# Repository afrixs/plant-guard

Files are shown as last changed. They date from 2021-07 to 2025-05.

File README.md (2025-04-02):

# Plant guard

Click to watch (https://www.youtube.com/watch?v=59vS7RXK-lc "Click to watch")

A simple plant watering machine.
Used parts:
  - Raspberry Pi 3 B+
  - Submersible Low Noise Motor Pump 3-6V
  - Motor driver l293d
  - Stepper motor 28BYJ-48 with driver
  - Silicon hose
  - Bucket
  - [3d-printed parts](models)
  - dupont cables, screws, ...

No sensors are used for now, you will need to set appropriate timing for the frequency and duration of the watering (Keep in mind the watering will be slower when the bucket is emptier).

Usage:
  1. Assemble using the datasheets of the components (GPIO pins for the pump driver are 5 (->IN1) and 6 (->IN2), GPIO pins for the stepper motor driver are 24, 23, 22, 27 (-> IN1, IN2, IN3, IN4)) and mount onto the bucket
  2. `ssh pi@raspberrypi.local`
  3. `git clone https://github.com/afrixs/plant-guard.git`
  4. `pip3 install python_crontab pyyaml portalocker`
  5. Set the arm to point directly outwards from the bucket
  6. `python3 plant-guard/pg_ws/src/pg_pump_crane/pg_pump_crane/pump_crane_keyboard.py`
  7. Use arrow keys to move the arm. Repeat the last arrow key stroke to stop. When the arm is above the plant being configured use 'f' key to set `angle_from`. Optionally move the arm a little bit and use 't' key to set `angle_to`. The arm will be moving between `angle_from` and `angle_to` during the watering so that water does not fall to a single spot only.
  8. Use 'p' key to start/stop the pump. Duration of pumping will be stored to `pump_dur`.
  9. Use 'Enter' key to create a watering job. Enter a name for the job and a crontab time entry
  10. The watering job is scheduled. Repeat 6.-8. for another plant
  11. Use 'l' key to list all jobs, 'd' key to delete a single job or 'x' key to delete all jobs
  12. Use 'q' or 'Esc' key to quit the job configuration client. Lock for controlling motors is released and scheduled jobs are free to run
  13. You can now use Ctrl+D to logout from ssh

Note: You may edit the jobs afterwards using `crontab -e` or `nano ~/plant_guard/jobs.yaml`.

Important note: don't turn the stepper motor manually after the first start or the configuration will be broken. If you need (or accidentally happen) to turn it, use `rm ~/plant_guard/save.txt; rm ~/plant_guard/save_backup.txt` and follow steps 5. - 12. to reconfigure (or turn the motor back to its original position, hoping the difference will not be critical).

Important note: Also when leaving the device to operate without your attendance for a longer time, prepare the place in a way that no firm or big leaves capable of blocking the movement of the arm will grow in its way.

First test was successful: Here are images of our plants before and after leaving the apartment for 9 days. I think they liked it

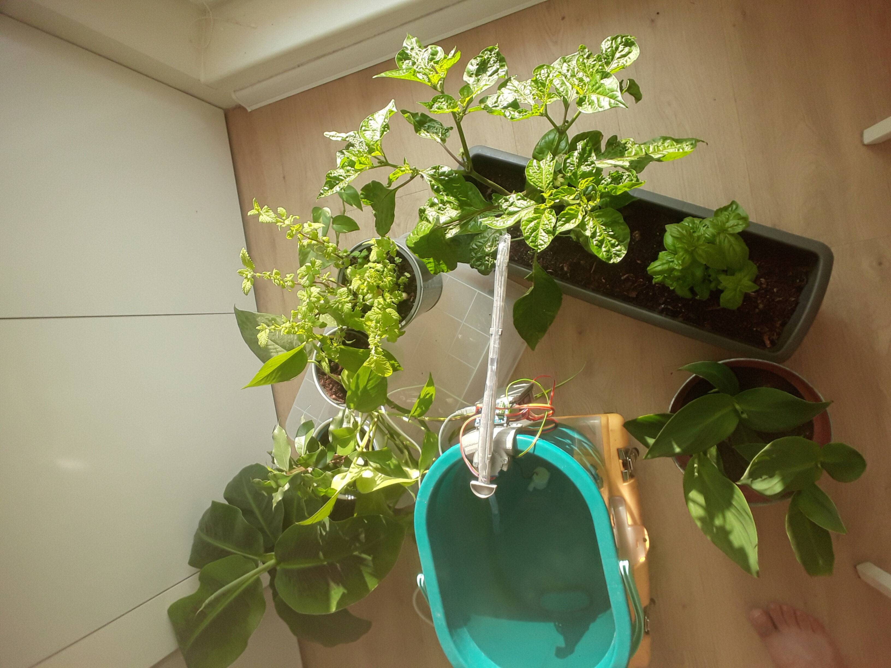
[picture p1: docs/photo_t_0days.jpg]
t = 0

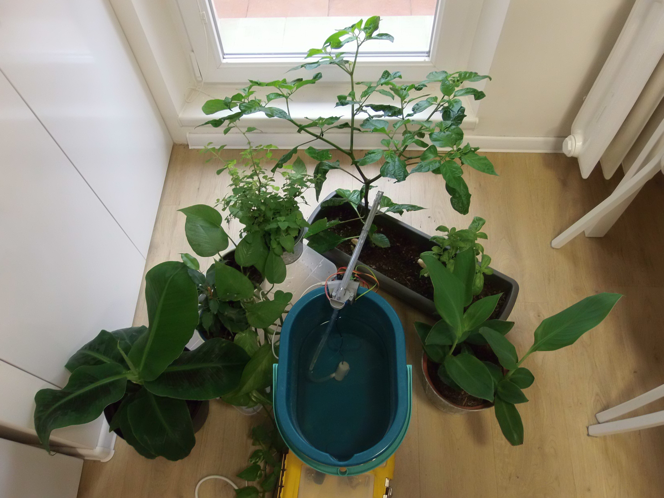
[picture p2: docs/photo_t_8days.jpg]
t = 9 days


sudo nano /boot/firmware/config.txt -> dtparam=spi=on
sudo raspi-config -> System Options -> Boot / Auto Login -> Console Autologin
sudo nano /etc/dphys-swapfile -> CONF_SWAPSIZE=4096, CONF_MAXSWAP=4096
sudo dphys-swapfile setup
mkdir .plant_guard
mkdir .ros
sudo ln -s /home/pi/.ros /root/.ros
sudo ln -s /home/pi/.plant_guard /root/.plant_guard
sudo ln -s /var/spool/cron/crontabs /root/.plant_guard_cron
tmp (TODO): nano .plant_guard/jobs.yaml
# add following 3 lines
pump_crane:
  __config: {}
  __type: pump_crane

sudo ./docker-build.bash
# or to run in background:
sudo apt install screen
sudo screen -dmS plant_guard_build /bin/bash -i -c "./docker-build.bash 2>>/root/build_docker.err 1>>/root/build_docker.out"
sudo tail -f /root/build_docker.err
# sudo screen -S plant_guard_build -X quit
Note: `docker-*.bash` must be run with `sudo`

sudo apt install screen
sudo crontab -e -> @reboot screen -DmS plant_guard bash -i -c "/home/pi/plant-guard/docker-run.bash 1>>/root/plant_guard_control_out.log 2>>/root/plant_guard_control_err.log"
sudo screen -S plant_guard -X quit

server:
```
sudo yum update
sudo yum install docker
sudo systemctl enable docker
sudo crontab -e -> @reboot sudo docker run --init --rm --net=host -p 7447:7447/tcp -p 8000:8000/tcp eclipse/zenoh:0.5.0-beta.9
```

client:
ros2 launch plantguard_bringup pump_crane_client.launch.py

testing on local machine:
sudo ./docker-build.bash --build-arg use_mocks=true
sudo ./docker-run.bash raspberry_pi:=false stream_over_internet:=false
ros2 launch plantguard_bringup pump_crane_client.launch.py stream_over_internet:=false

(for building on native system):
rosdep update --include-eol-distros
rosdep install --from-paths src --ignore-src --rosdistro iron --skip-keys libcamera -y

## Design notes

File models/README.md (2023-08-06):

# Models
These are models to be 3D-printed for the robot. Basically you need to print each `.3mf` file once.
I use [PrusaSlicer](https://www.prusa3d.com/) for slicing and generating gcode.

## Editing
Probably (unless you happen to have same bucket and components as me) you'll need to edit
some parts. Currently I suggest using [toponaming](https://github.com/FreeCAD/FreeCAD/tree/development/toponaming) branch of
FreeCAD and (to prevent headaches) **not mapping anything on 3D features**, i.e. project only geometry from sketches and
use DatumPlanes and parametric expressions to achieve proper structure, otherwise recomputing hell will come upon you
with refernces jumping from one feature to another etc.

After editing and exporting the models, there is a `Reload from disk` feature in PrusaSlicer.

After reloading from disk you will want to add supports to all overhangs under 40˚ for `arm-Arm.stl` and 50˚ for `arm-Base.stl` and to disable supports in screw and nut holes, because 3D printer usually can handle small bridges like those and much of filament and printing time can be spared. Final supports could be like what you see (green color) in the image below.

Note: I haven't printed this version of `arm-Base.stl` model (I printed just a previous buggy version where the roof for RPi and motor driver didn't lean), so maybe you will need to play with print params (increase brim etc.) to print the model successfully.

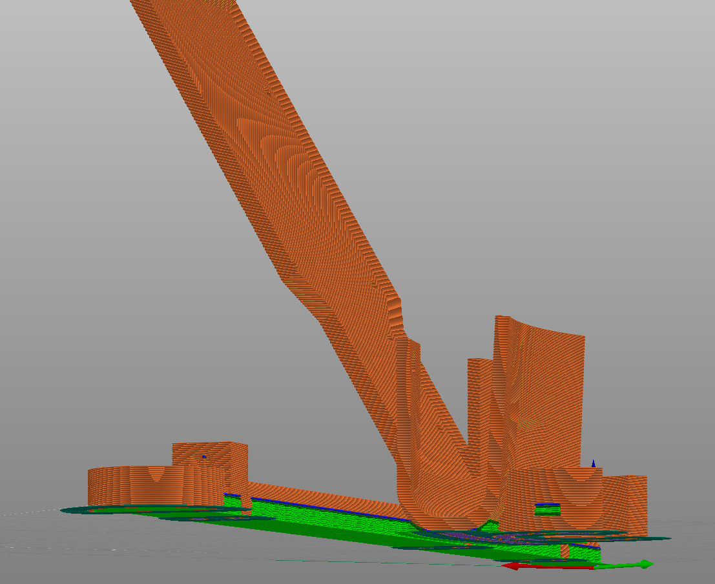
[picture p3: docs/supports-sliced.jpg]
t = 0


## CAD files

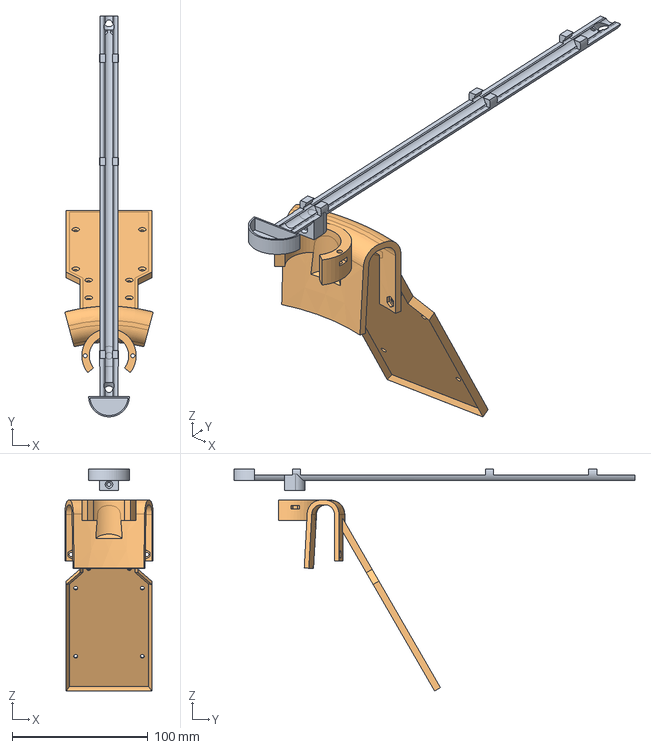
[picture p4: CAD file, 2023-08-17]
models/arm.FCStd
65.1 x 295.0 x 163.4 mm
Arm
Base

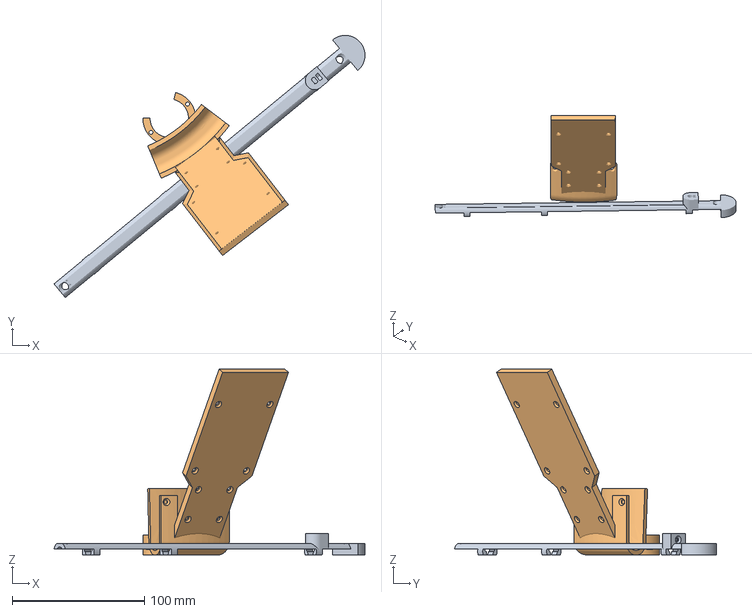
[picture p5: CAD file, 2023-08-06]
models/arm-Arm.3mf
235.3 x 198.3 x 140.5 mm
arm-Arm.stl
arm-Base.stl

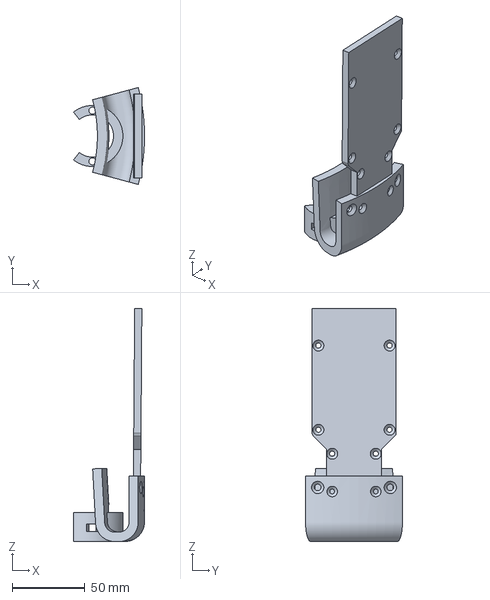
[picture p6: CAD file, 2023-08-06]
models/arm-Base.3mf
48.9 x 66.7 x 160.5 mm

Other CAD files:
models/pump-crane-plants.FCStd
models/arm-Arm.stl
models/arm-Base.stl

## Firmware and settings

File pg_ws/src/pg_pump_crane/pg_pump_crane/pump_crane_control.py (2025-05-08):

import rclpy
from rclpy.time import Duration, Time
from rclpy.node import Node
from rclpy.qos import QoSProfile, ReliabilityPolicy
from std_msgs.msg import Int32, Bool
# from pg_msgs.srv import GetJobs, EditJob
from pg_msgs.msg import MeasurementHeader
from pg_pump_crane_msgs.action import PerformJob
from pg_msgs.msg import Float64Stamped, BoolStamped
from rclpy.action import ActionServer, CancelResponse, GoalResponse
from rclpy.callback_groups import MutuallyExclusiveCallbackGroup
from rclpy.executors import MultiThreadedExecutor
from pg_pump_crane.pump_crane import PumpCrane
import portalocker
from pathlib import Path
from threading import Lock, Thread, Condition

class PumpCraneControl(Node):
  def __init__(self):
    super().__init__('pump_crane_control')

    self.angle_pub = self.create_publisher(Float64Stamped, 'angle', 1) #QoSProfile(depth=1, reliability=ReliabilityPolicy.BEST_EFFORT))
    self.pump_pub = self.create_publisher(BoolStamped, 'pump', 1)
    # TODO: pump_pub

    self.pump_crane = PumpCrane(False, stepperPosCallback=lambda pos: self.stepper_pos_callback(pos), pumpCallback=lambda pumping: self.pump_callback(pumping))
    self.pump_crane.setKeyboardListening(True)
    self.pump_crane.cleanupHW()

    self.movement_dir_sub = self.create_subscription(Int32, 'movement_dir_cmd', self.movement_dir_cmd_callback, 1)
    self.pump_sub = self.create_subscription(Bool, 'pump_cmd', self.pump_cmd_callback, 1)

    # self.get_jobs_server = self.create_service(GetJobs, 'get_jobs', self.get_jobs_callback)
    # self.edit_job_server = self.create_service(EditJob, 'edit_job', self.edit_job_callback)

    self.perform_job_server = ActionServer(
      self,
      PerformJob,
      'perform_job',
      self.perform_job_callback,
      goal_callback=self.perform_job_goal_callback,
      cancel_callback=self.perform_job_cancel_callback,
      callback_group=MutuallyExclusiveCallbackGroup()
    )

    self.pump_crane_lock = Lock()
    self.canceled_jobs = []  # cannot be a set() because UUIDs are not hashable
    self.jobs_queue = []
    self.jobs_queue_condition = Condition()
    self.current_job_goal_handle = None
    self.current_job_goal_handle_lock = Lock()

    self.watchdog_timer = self.create_timer(0.5, self.watchdog_callback)
    self.last_pump_time = None
    self.last_movement_time = None

  def destroy_node(self):
    self.pump_crane.setKeyboardListening(False)
    self.pump_crane.stopPump()
    self.pump_crane.setMovementDir(0)
    self.pump_crane.cleanup()
    try:
      self.pump_crane_lock.release()
    except:
      pass
    super().destroy_node()

  def watchdog_callback(self):
    if self.last_pump_time is not None and self.get_clock().now() - self.last_pump_time > Duration(seconds=0.5):
      self.get_logger().warn("Connection lost, stopping pump")
      self.pump_crane.stopPump()
      self.last_pump_time = None
      if self.last_movement_time is None:
        self.pump_crane.cleanupHW()
        self.pump_crane_lock.release()
    if self.last_movement_time is not None and self.get_clock().now() - self.last_movement_time > Duration(seconds=0.5):
      self.get_logger().warn("Connection lost, stopping movement")
      self.pump_crane.setMovementDir(0)
      self.last_movement_time = None
      if self.last_pump_time is None:
        self.pump_crane.cleanupHW()
        self.pump_crane_lock.release()

  def movement_dir_cmd_callback(self, msg: Int32):
    was_moving = self.last_movement_time is not None
    self.last_movement_time = self.get_clock().now() if msg.data != 0 else None
    if self.last_movement_time is not None and not was_moving and self.last_pump_time is None:
      self.pump_crane_lock.acquire()
      self.pump_crane.initHW()
    self.pump_crane.setMovementDir(msg.data)
    if self.last_movement_time is None and was_moving and self.last_pump_time is None:
      self.pump_crane.cleanupHW()
      self.pump_crane_lock.release()

  def pump_cmd_callback(self, msg: Bool):
    was_pumping = self.last_pump_time is not None
    if msg.data:
      self.last_pump_time = self.get_clock().now()
      if not was_pumping and self.last_movement_time is None:
        self.pump_crane_lock.acquire()
        self.pump_crane.initHW()
      self.pump_crane.startPump()
    else:
      self.pump_crane.stopPump()
      self.last_pump_time = None
      if was_pumping and self.last_movement_time is None:
        self.pump_crane.cleanupHW()
        self.pump_crane_lock.release()

  def perform_job_goal_callback(self, goal: PerformJob.Goal):
    self.get_logger().info(f"Received PerformJob goal: ({goal.job.angle_from}˚ <-> {goal.job.angle_to}°) x {goal.job.pump_duration} s")
    return GoalResponse.ACCEPT

  def perform_job_cancel_callback(self, goal_handle):
    self.get_logger().info(f"PerformJob goal {goal_handle.goal_id} canceling")
    with self.jobs_queue_condition:
      if goal_handle.is_active:
        self.canceled_jobs.append(goal_handle.goal_id)
        self.jobs_queue_condition.notify_all()
    return CancelResponse.ACCEPT

  def perform_job_callback(self, goal_handle):
    goal: PerformJob.Goal = goal_handle.request
    result = PerformJob.Result()

    with self.jobs_queue_condition:
      self.jobs_queue.append(goal_handle.goal_id)
      if len(self.jobs_queue) > 1:
        self.get_logger().info(f"PerformJob goal {goal_handle.goal_id} queued")
        feedback = PerformJob.Feedback()
        feedback.stage = PerformJob.Feedback.STAGE_QUEUED
        goal_handle.publish_feedback(feedback)

        while rclpy.ok() and not (goal_handle.is_cancel_requested or goal_handle.goal_id in self.canceled_jobs) and self.jobs_queue[0] != goal_handle.goal_id:
          self.jobs_queue_condition.wait()

    if rclpy.ok() and not goal_handle.is_cancel_requested:
      self.get_logger().info(f"Executing PerformJob goal {goal_handle.goal_id}...")
      self.pump_crane_lock.acquire()
      self.pump_crane.initHW()

      with self.current_job_goal_handle_lock:
        self.current_job_goal_handle = goal_handle
        feedback = PerformJob.Feedback()
        feedback.stage = PerformJob.Feedback.STAGE_APPROACHING
        goal_handle.publish_feedback(feedback)

      self.pump_crane.allowMovement()
      water_thread = Thread(
        target=self.pump_crane.water,
        args=(goal.job.angle_from, goal.job.angle_to, goal.job.pump_duration, False),
        daemon=True)
      water_thread.start()

      while rclpy.ok() and not goal_handle.is_cancel_requested and water_thread.is_alive():
        # feedback = PerformJob.Feedback()
        # feedback.current_duration = (self.get_clock().now() - start).nanoseconds / 1e9
        # goal_handle.publish_feedback(feedback)
        self.get_clock().sleep_for(Duration(seconds=0.1))
      if water_thread.is_alive():
        self.pump_crane.terminateMovement()
      water_thread.join()

      with self.current_job_goal_handle_lock:
        self.current_job_goal_handle = None
      self.pump_crane.cleanupHW()
      self.pump_crane_lock.release()

    with self.jobs_queue_condition:
      self.jobs_queue.remove(goal_handle.goal_id)
      self.jobs_queue_condition.notify_all()

      # must be inside the lock to prevent adding the uuid to canceled_jobs after the job is done
      try:
        self.canceled_jobs.remove(goal_handle.goal_id)
      except ValueError:
        pass
      if goal_handle.is_cancel_requested:
        goal_handle.canceled()
      else:
        goal_handle.succeed()
    return result

  def stepper_pos_callback(self, pos):
    self.angle_pub.publish(Float64Stamped(header=MeasurementHeader(stamp=self.get_clock().now().to_msg()), data=pos))

  def pump_callback(self, pumping):
    self.get_logger().info("pumping: " + str(pumping))
    self.pump_pub.publish(BoolStamped(header=MeasurementHeader(stamp=self.get_clock().now().to_msg()), data=pumping))
    if pumping:
      with self.current_job_goal_handle_lock:
        if self.current_job_goal_handle is not None and self.current_job_goal_handle.is_active:
          feedback = PerformJob.Feedback()
          feedback.stage = PerformJob.Feedback.STAGE_WATERING
          self.current_job_goal_handle.publish_feedback(feedback)

def main(args=None):
  rclpy.init(args=args)
  node = PumpCraneControl()
  executor = MultiThreadedExecutor(12)
  executor.add_node(node)
  try:
    node.get_logger().info('Beginning client, shut down with CTRL-C')
    executor.spin()
  except KeyboardInterrupt:
    node.get_logger().info('Keyboard interrupt, shutting down.\n')
  node.destroy_node()
  rclpy.shutdown()

if __name__ == '__main__':
  main()

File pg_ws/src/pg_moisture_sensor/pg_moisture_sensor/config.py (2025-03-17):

# /*****************************************************************************
# * | File        :	  EPD_1in54.py
# * | Author      :   Waveshare team
# * | Function    :   Hardware underlying interface
# * | Info        :
# *----------------
# * |	This version:   V1.0
# * | Date        :   2019-01-24
# * | Info        :   
# ******************************************************************************/
# Permission is hereby granted, free of charge, to any person obtaining a copy
# of this software and associated documnetation files (the "Software"), to deal
# in the Software without restriction, including without limitation the rights
# to use, copy, modify, merge, publish, distribute, sublicense, and/or sell
# copies of the Software, and to permit persons to  whom the Software is
# furished to do so, subject to the following conditions:
#
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


import spidev
import RPi.GPIO as GPIO
import time

# Pin definition
RST_PIN         = 18
CS_PIN       = 4  # 22
DRDY_PIN        = 17

# SPI device, bus = 0, device = 0
SPI = spidev.SpiDev(0, 0)

def digital_write(pin, value):
    GPIO.output(pin, value)

def digital_read(pin):
    return GPIO.input(DRDY_PIN)

def delay_ms(delaytime):
    time.sleep(delaytime // 1000.0)

def spi_writebyte(data):
    SPI.writebytes(data)
    
def spi_readbytes(reg):
    return SPI.readbytes(reg)
    

def module_init():
    GPIO.setmode(GPIO.BCM)
    GPIO.setwarnings(False)
    GPIO.setup(RST_PIN, GPIO.OUT)
    GPIO.setup(CS_PIN, GPIO.OUT)
    #GPIO.setup(DRDY_PIN, GPIO.IN)
    GPIO.setup(DRDY_PIN, GPIO.IN, pull_up_down=GPIO.PUD_UP)
    SPI.max_speed_hz = 20000
    SPI.mode = 0b01
    return 0;

### END OF FILE ###

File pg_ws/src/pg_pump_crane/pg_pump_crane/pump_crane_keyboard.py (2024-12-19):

#!/usr/bin/env python3
import pg_msgs.msg

#pip3 install python_crontab pyyaml portalocker
from pump_crane import PumpCrane
from crontab import CronTab, CronSlices
import yaml
import portalocker
from pathlib import Path
import sys,tty,termios
import getpass
import re
import time
from pg_job_management.jobs_common import *
from pg_msgs.msg import Device
# from pynput import keyboard

pumpStartTime = time.time()
pumpingDuration = 0
angleFrom = -1
angleTo = -1
pumpRunning = False
DEVICE_NAME = "pump_crane"
JOB_PREFIX = JOB_CRON_PREFIX+DEVICE_NAME+"."

pumpCrane = None

def on_press(k):
  global pumpStartTime
  global pumpingDuration
  global angleFrom
  global angleTo
  global pumpRunning
  # if key == keyboard.Key.esc:
  # if k == 'esc':
  #   if keyboardListening:
  #     print("Stopping keyboard control. Press Enter to start keyboard control again")
  #     keyboardListening = False
  #   else:
  #     print("Stopping keyboard listening")
  #     return False
  # if key == keyboard.Key.enter:
  if k == 'return':
    if angleTo == -1 and angleFrom == -1:
      print("first press 'f' or 't' to set angleFrom or angleTo")
      return True
    if pumpingDuration == 0:
      print("first press and hold 'p' to set pumping duration")
      return True
    print("Enter a name of the new job")
    name = input()
    try:
      with open(JOBS_YAML_PATH) as file:
        jobsData = yaml.full_load(file)
    except:
      jobsData = {}
    if jobsData is None:
      jobsData = {}
    if DEVICE_NAME not in jobsData:
      jobsData[DEVICE_NAME] = {'__type': Device.TYPE_PUMP_CRANE}
    jobsData[DEVICE_NAME][name] = {
        'angle_from': angleFrom if angleFrom != -1 else angleTo,
        'angle_to': angleTo if angleTo != -1 else angleFrom,
        'pump_dur': pumpingDuration
      }
    with open(JOBS_YAML_PATH, 'w') as file:
      yaml.dump(jobsData, file)
    
    print("Enter schedule\nminute hour day_of_month month day_of_week\nexample (every friday at 6AM and 6PM): 0 6,18 * * Fri)")
    schedule = input()
    while not CronSlices.is_valid(schedule):
      print("Invalid schedule")
      schedule = input()
    cron = CronTab(user=getpass.getuser())
    # job = cron.new(command='python3 ~/plant_guard/plant_guard_job.py '+name, comment=JOB_PREFIX+name)
    job = cron.new(command='bash -i -c "r2pg && ros2 run pg_pump_crane pump_crane_job_client --ros-args -r __ns:=/'+DEVICE_NAME+' -p job_name:='+name+
                           '" 2>>~/plant_guard/err.log 1>>~/plant_guard/out.log', comment=JOB_PREFIX + name)
    job.setall(schedule)
    cron.write()
    print("Added job "+name+"  "+schedule+"  "+str(jobsData[DEVICE_NAME][name]))

  # try:
  #   k = key.char  # single-char keys
  # except:
  #   k = key.name  # other keys
  if k == 'l':
    print("Plant guard jobs:")
    cron = CronTab(user=getpass.getuser())
    try:
      with open(JOBS_YAML_PATH) as file:
        jobsData = yaml.full_load(file)
    except:
      jobsData = {}
    if jobsData is None:
      jobsData = {}
    for job in cron.find_comment(re.compile("^" + JOB_PREFIX.replace(".", "\\.") + ".*$")):
      name = job.comment[len(JOB_PREFIX):]
      print(name+"  "+str(job.slices)+"  "+(str(jobsData[DEVICE_NAME][name]) if DEVICE_NAME in jobsData and name in jobsData[DEVICE_NAME] else "No data!"))
  if k == 'd':
    print("Enter the name of the job to be deleted")
    name = input()
    cron = CronTab(user=getpass.getuser())
    if cron.remove_all(comment=JOB_PREFIX+name) == 0:
      print("No job found")
    else:
      print("Deleted job")
    cron.write()

    try:
      with open(JOBS_YAML_PATH) as file:
        jobsData = yaml.full_load(file)
    except:
      jobsData = {}
    if jobsData is None:
      jobsData = {}
    if DEVICE_NAME in jobsData and name in jobsData[DEVICE_NAME]:
      del jobsData[DEVICE_NAME][name]
      with open(JOBS_YAML_PATH, 'w') as file:
        yaml.dump(jobsData, file)
      print("Deleted data")
    else:
      print("No data found")
  if k == 'x':
    cron = CronTab(user=getpass.getuser())
    if cron.remove_all(comment=re.compile("^" + JOB_PREFIX.replace(".", "\\.") + ".*$")) == 0:
      print("No job found for " + DEVICE_NAME)
    else:
      print("Deleted all jobs for " + DEVICE_NAME)
    cron.write()
    try:
      with open(JOBS_YAML_PATH) as file:
        jobsData = yaml.full_load(file)
    except:
      jobsData = {}
    if jobsData is None:
      jobsData = {}
    if DEVICE_NAME in jobsData:
      del jobsData[DEVICE_NAME]
      with open(JOBS_YAML_PATH, 'w') as file:
        yaml.dump(jobsData, file)
      print("Deleted all job data for " + DEVICE_NAME)
    else:
      print("No job data found for " + DEVICE_NAME)

  if k == 'left':
    pumpCrane.setMovementDir(0 if pumpCrane.getMovementDir() == 1 else 1)
  if k == 'right':
    pumpCrane.setMovementDir(0 if pumpCrane.getMovementDir() == -1 else -1)
  if k == 'p':
    if pumpRunning:
      pumpRunning = False
      pumpCrane.stopPump()
      pumpingDuration = time.time() - pumpStartTime
      print("Pumping time: " + str(pumpingDuration))
    else:
      print("Starting pump")
      pumpRunning = True
      pumpCrane.startPump()
      pumpStartTime = time.time()
  if k == 'f':
    angleFrom = pumpCrane.getCurrentAngle()
    print("Angle from: " + str(angleFrom))
  if k == 't':
    angleTo = pumpCrane.getCurrentAngle()
    print("Angle to: " + str(angleTo))
  if k == 'h':
    print("left - move left\nright - move right\nl - list jobs\nx - delete all jobs\nd - delete job\nf - set angleFrom\nt - set angleTo\np - start/stop pump\nenter - save job\nesc/q - quit")


  return True

# def on_release(key):
#   global pumpingDuration
#   global pumpRunning
#   try:
#     k = key.char  # single-char keys
#   except:
#     k = key.name  # other keys
#   if (k == 'left' and getKeyboardDir() == 1) or (k == 'right' and getKeyboardDir() == -1):
#     setKeyboardDir(0)
#     print("Angle: " + str(getCurrentAngleInternalScale()))
#   if k == 'p' and pumpRunning:
#     pumpRunning = False
#     stopPump()
#     pumpingDuration = time.time() - pumpStartTime
#     print("Pumping time: " + str(pumpingDuration))
#   if key == keyboard.Key.esc:
#     return False
#   if k == 'k':
#     print("Keyboard test: on release")

#   return True

def getkey():
  old_settings = termios.tcgetattr(sys.stdin)
  tty.setcbreak(sys.stdin.fileno())
  try:
    while True:
      b = os.read(sys.stdin.fileno(), 3).decode()
      if len(b) == 3:
        k = ord(b[2])
      else:
        k = ord(b)
      key_mapping = {
          127: 'backspace',
          10: 'return',
          32: 'space',
          9: 'tab',
          27: 'esc',
          65: 'up',
          66: 'down',
          67: 'right',
          68: 'left'
      }
      return key_mapping.get(k, chr(k))
  finally:
      termios.tcsetattr(sys.stdin, termios.TCSADRAIN, old_settings)
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

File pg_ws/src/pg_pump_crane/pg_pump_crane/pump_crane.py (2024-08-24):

import RPi.GPIO as GPIO
import time
import math
from threading import Lock, Thread, Event
from pathlib import Path

class PumpCrane:
  lock = Lock()
  keyboardListening = False
  movementDir = 0
  movementTerminated = Event()
  rikt = []

  PUMP_PIN = 5
  PUMP_REV_PIN = 6

  STEPPER_PINS = [24, 23, 22, 27]
  STEPS = [[1,0,0,0],[1,1,0,0],[0,1,0,0],[0,1,1,0],[0,0,1,0],[0,0,1,1],[0,0,0,1],[1,0,0,1]]
  currentStep = 0
  currentAngle = 0
  fullRot = 512*8

  stepperSleepDur = 0.005
  hardwareInitialized = False

  def __init__(self, exitOnLoadFailure, stepperPosCallback=lambda pos: None, pumpCallback=lambda pumping: None):
    self.stepperPosCallback = stepperPosCallback
    self.pumpCallback = pumpCallback
    if not self.readSavedData(False) and not self.readSavedData(True):
      if exitOnLoadFailure:
        print("ERROR: No saved state file found")
        exit(-1)
      else:
        print("WARNING: No saved state file found. This is ok if running for the first time")
    self.initHW()

  def cleanup(self):
    self.cleanupHW()

  def initHW(self):
    with self.lock:
      GPIO.setmode(GPIO.BCM)
      self.initPump()
      self.initStepper()
      self.hardwareInitialized = True

  def cleanupHW(self):
    with self.lock:
      self.hardwareInitialized = False
      GPIO.cleanup()

  def initPump(self):
    GPIO.setup(self.PUMP_PIN, GPIO.OUT)
    GPIO.output(self.PUMP_PIN, GPIO.LOW)
    GPIO.setup(self.PUMP_REV_PIN, GPIO.OUT)
    GPIO.output(self.PUMP_REV_PIN, GPIO.LOW)
    pass

  def startPump(self):
    with self.lock:
      if not self.hardwareInitialized:
        print("startPump ERROR: Hardware not initialized")
        return
      GPIO.output(self.PUMP_PIN, GPIO.HIGH)
    self.pumpCallback(True)

  def stopPump(self):
    with self.lock:
      if self.hardwareInitialized:
        GPIO.output(self.PUMP_PIN, GPIO.LOW)
    self.pumpCallback(False)

  def computeChecksum(self):
    return 0xFFFFFFFF - (self.currentStep + self.currentAngle)

  def saveFilePath(self, backup):
    return str(Path.home())+'/plant_guard/save'+('_backup.txt' if backup else '.txt')

  def readSavedData(self, backup):
    try:
      with open(self.saveFilePath(backup)) as file:
        self.currentStep = int(file.readline())
        self.currentAngle = int(file.readline())
        checksum = int(file.readline())
        if checksum != self.computeChecksum():
          raise
    except:
      return False
    return True

  def writeSavedData(self, backup):
    with open(self.saveFilePath(backup), 'w') as file:
      file.writelines([str(self.currentStep)+'\n', str(self.currentAngle)+'\n', str(self.computeChecksum())+'\n'])

  def initStepper(self):
    for p in self.STEPPER_PINS:
      GPIO.setup(p, GPIO.OUT)
    self.updateStepper()

  def updateStepper(self):
    if self.hardwareInitialized:
      self.writeSavedData(False)
      self.writeSavedData(True)
      self.stepperPosCallback(self.getCurrentAngle())
      for (p, v) in zip(self.STEPPER_PINS, self.STEPS[self.currentStep]):
        GPIO.output(p, GPIO.HIGH if v == 1 else GPIO.LOW)

  def degAngle(self, deg):
    return round(deg*512.0/45.0)

  def rotateSteps(self, stepsCnt):
    with self.lock:
      if not self.hardwareInitialized:
        print("rotateSteps ERROR: Hardware not initialized")
        return
      for _ in range(abs(stepsCnt)):
        if stepsCnt > 0:
          self.currentStep = (self.currentStep+1)%len(self.STEPS)
          self.currentAngle = (self.currentAngle+1)%self.fullRot
        else:
          self.currentStep = (self.currentStep - 1 + len(self.STEPS))%len(self.STEPS)
          self.currentAngle = (self.currentAngle - 1 + self.fullRot)%self.fullRot
        self.updateStepper()
        time.sleep(self.stepperSleepDur)
        if self.movementTerminated.is_set():
          break

  def rotateTo(self, angle):
    while angle >= self.fullRot:
      angle -= self.fullRot
    while angle < 0:
      angle += self.fullRot

    with self.lock:
      stepsCnt = angle - self.currentAngle
    while stepsCnt > self.fullRot/2:  # 'if' is good enough since angle and currentAngle are in [0, 2pi)
      stepsCnt -= self.fullRot
    while stepsCnt < -self.fullRot/2:  # 'if' is good enough since angle and currentAngle are in [0, 2pi)
      stepsCnt += self.fullRot
    # don't rotate through 360 degrees because of hose and (future) cables
    if self.currentAngle <= self.fullRot/2 and angle > self.fullRot/2 and stepsCnt > 0:
      stepsCnt -= self.fullRot
    elif self.currentAngle > self.fullRot/2 and angle <= self.fullRot/2 and stepsCnt < 0:
      stepsCnt += self.fullRot

    self.rotateSteps(stepsCnt)

  def patrol(self, angle1, angle2):
    if angle1 == angle2:
      return
    while not self.movementTerminated.is_set():
      self.rotateTo(angle2)
      if not self.movementTerminated.is_set():
        self.rotateTo(angle1)

  def allowMovement(self):
    self.movementTerminated.clear()

  def terminateMovement(self):
    self.movementTerminated.set()

  def water(self, angle1, angle2, dur, auto_allow=True):
    if auto_allow:
      self.movementTerminated.clear()
    angle1 = self.toInternalAngleScale(angle1)
    angle2 = self.toInternalAngleScale(angle2)
    print("watering from "+str(angle1)+" to "+str(angle2)+" dur "+str(dur))
    self.rotateTo(angle1)
    if not self.movementTerminated.is_set():
      self.startPump()
      t = Thread(target=self.patrol, args=(angle1, angle2))
      t.start()
      self.movementTerminated.wait(dur)
      self.movementTerminated.set()
      t.join()
    self.movementTerminated.clear()
    self.stopPump()
    time.sleep(1.0)

  def setKeyboardListening(self, kl):
    if self.keyboardListening != kl:
      self.keyboardListening = kl
      if kl:
        self.rikt = Thread(target=self.rotateIfKey)
        self.rikt.start()
      else:
        self.rikt.join()

  def setMovementDir(self, kd):
    self.movementDir = kd
  def getMovementDir(self):
    return self.movementDir

  def getCurrentAngleInternalScale(self):
    return self.currentAngle

  def getCurrentAngle(self):
    return (self.currentAngle - (self.fullRot if self.currentAngle > self.fullRot/2 else 0.0))/self.fullRot*(math.pi*2)

  def toInternalAngleScale(self, angle):
    a = round(angle/(math.pi*2)*self.fullRot)
    return a + (self.fullRot if a < 0 else 0)
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

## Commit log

2021-06-15 simple working solution (user interface for cron jobs and yaml params configuration, stepper motor and pump control) with no sensors and no web
2021-06-15 added models
    [arm.FCStd, arm.stl, motor-holder-Body003.stl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]
2023-08-06 fixed freecad models to be easy to edit, made RPi/motor driver roof lean away from bucket
    [arm-Arm.3mf, arm-Arm.stl, arm-Base.3mf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]
2023-08-17 fixed arm model chamfers
    [arm.FCStd]
2023-08-17 added ROS2 packages for publishing H264 video from USB camera
2024-07-23 made powered by ROS2 Iron
    * remote monitoring using camera
    * bag recording and playing via bagtube
    * added GUI in form of RViz plugins
    * added more sophisticated jobs management from a remote device, allowing multiple machines
    of different types in the future
    * added scripts for building and running docker images
    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
2024-07-25 reduced build threads to 1
2024-08-29 updated to use RPi-camera compatible camera_ros package instead of usb_cam
2024-12-19 refactored, devices made modular, added moisture_sensor
2025-01-18 pump crane crash fixed, added setup instructions to README, added zenoh respawn
    [pump_crane_control.py]
2025-03-11 fixed docker warnings, updated readme, updated camera params
2025-03-13 RPi camera encoder made working
2025-03-17 moisture sensor fixes
2025-04-02 mocked build option, fixed device creation, refresh success feedback
2025-05-08 added state server and conditional jobs
    [planks.ods, pump-crane-plants.FCStd]
